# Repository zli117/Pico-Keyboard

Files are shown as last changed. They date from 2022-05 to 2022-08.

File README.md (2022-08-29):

# Pico-Keyboard

A hot-swappable mechanical keyboard built from scratch with Pi Pico board, and 3D printed case, with a very configurable firmware. The firmware is in a separate repo: https://github.com/zli117/PicoMK and can be reused for other RP2040 keyboards.

# Pictures

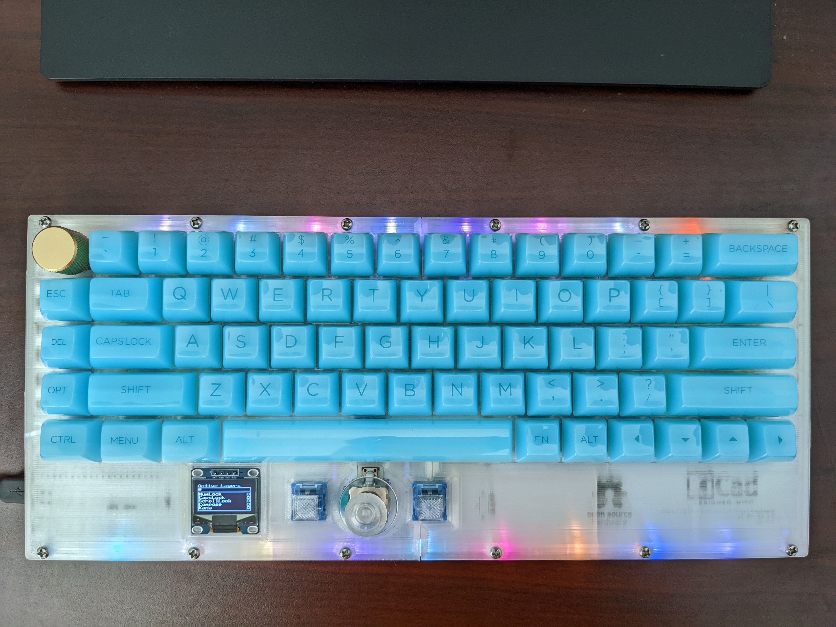
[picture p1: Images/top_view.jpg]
Top View

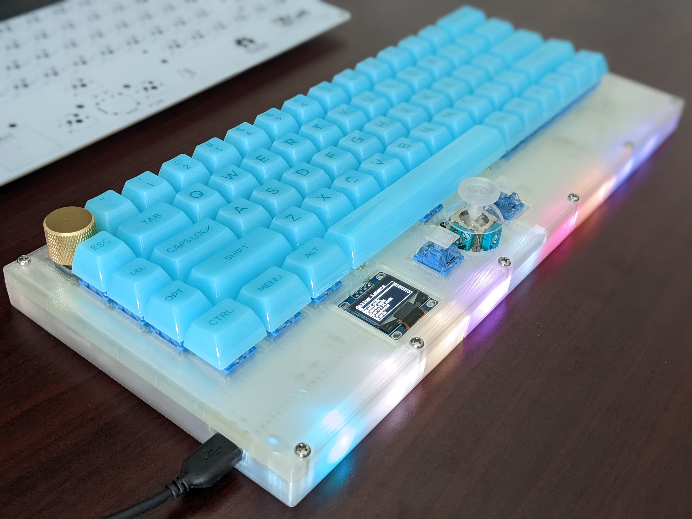
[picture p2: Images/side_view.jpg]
Side View


## PCB

PCB

## Case

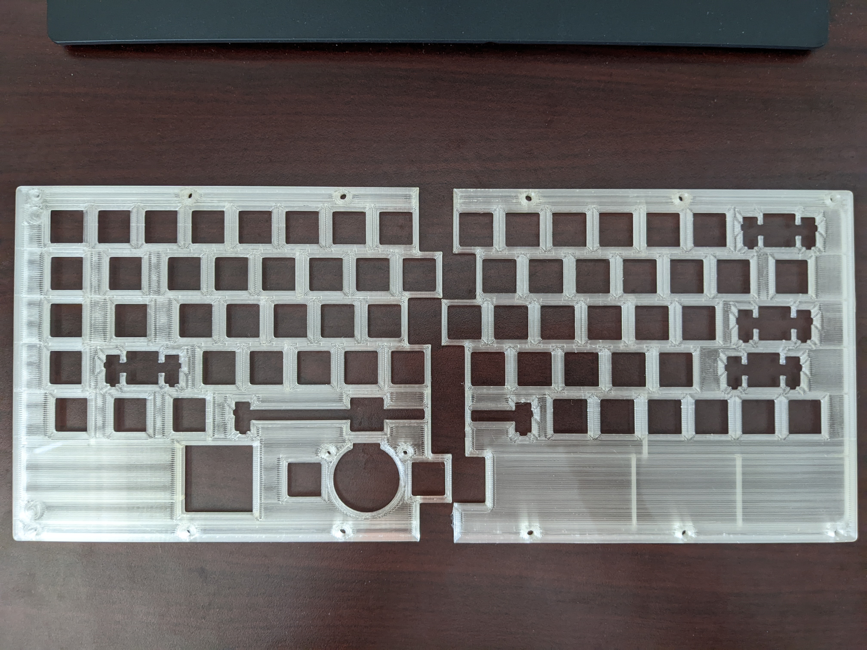
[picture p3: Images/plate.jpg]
Plate

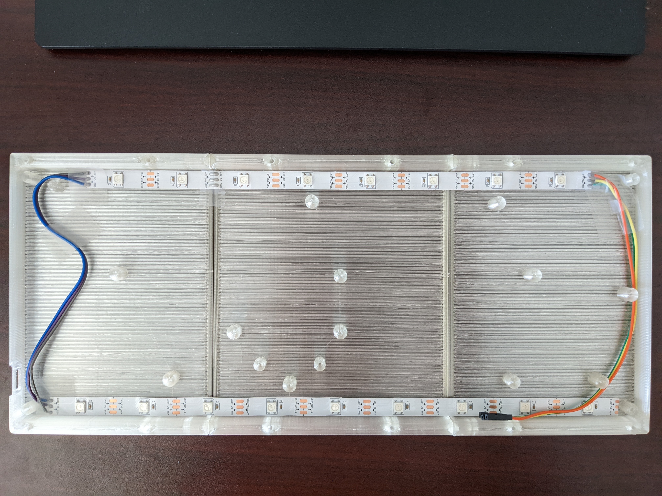
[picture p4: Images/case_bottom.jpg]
Bottom


## Build Pictures

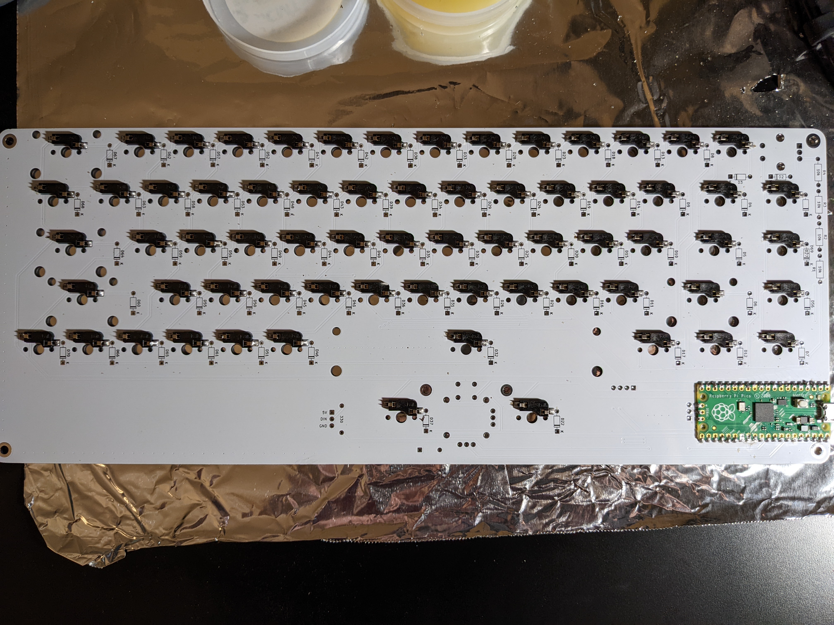
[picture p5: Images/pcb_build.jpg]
PCB Solder

Bottom View

# Overall Cost Breakdown

In total per keyboard material cost is roughly $129.57

 * 5 PCB from JLCPCB with shipping: $39.52. Roughly $7.9 per board.
 * 100 hot-swappable PCB socket: $14.50. Used 68, so total $9.86.
 * Pi Pico: $4.99.
 * EC11 Rotary Encoder: $1.10 each.
 * COM-09032 Joystick: $4.50 each.
 * 100 1N4148 diodes: $4.99. Used 70 so $3.50.
 * 150 WS2812B: $14.49. Used 17, so total $1.64.
 * 3D printed case. Each part weight about 50g and there are 5 (2 for plate, and 3 for bottom). Total weight 250g roughly $6.
 * SSD1306 white color: $3 each.
 * GMMK encoder knob: $10.
 * Clear joystick knob: $5.
 * Stabilizers: $16.99 per set.
 * Akko clear translucent keycap: $39.99.
 * Akko blue switch: $9.99 per 45. Used 68, so total $15.10
 
# Build Instructions

## PCB
PCB is designed with KiCAD 6, and everything is under the [PCB](PCB/) folder. Pre-plotted files that can be uploaded to board factory are in 
`Gerber.zip` file. However, different factory may have different plotting settings, so it's recommended to replot with KiCad following factory's instruction. The provided one is for JLCPCB. 

## Case
Case is designed with Fusion 360. The file ends in `.f3z` contains the original Fusion 360 source. My build used SUNLU Clear PLA and is sliced with Cura. I put screw holes on the bottom to secure the PCB, but in practice it's not necessary to screw down the PCB once you've installed switches. So those are optional. The screws between plate and bottom are not optional however.

## Firmware
Firmware is in a separate repo: [PicoMK](https://github.com/zli117/PicoMK). Please see the instruction on how to configure and build the firmware there. 

# PCB Library Licenses

 * Pico symbol, footprint from https://github.com/ncarandini/KiCad-RP-Pico under CC-BY-SA 4.0. 3D model for Pico is obtained from Raspberry Pi Foundation.
 * COM-09032 symbol, footprint and 3D models are from SnapEDA.
 * Key switch footprints and 3D models are from https://github.com/perigoso/keyswitch-kicad-library 
 * Other symbols are from KiCad library which is under CC-BY-SA 4.0 license. 

This work is licensed under a
[Creative Commons Attribution-ShareAlike 4.0 International License][cc-by-sa].

[][cc-by-sa]

[cc-by-sa]: http://creativecommons.org/licenses/by-sa/4.0/
[cc-by-sa-image]: https://licensebuttons.net/l/by-sa/4.0/88x31.png
[cc-by-sa-shield]: https://img.shields.io/badge/License-CC%20BY--SA%204.0-lightgrey.svg

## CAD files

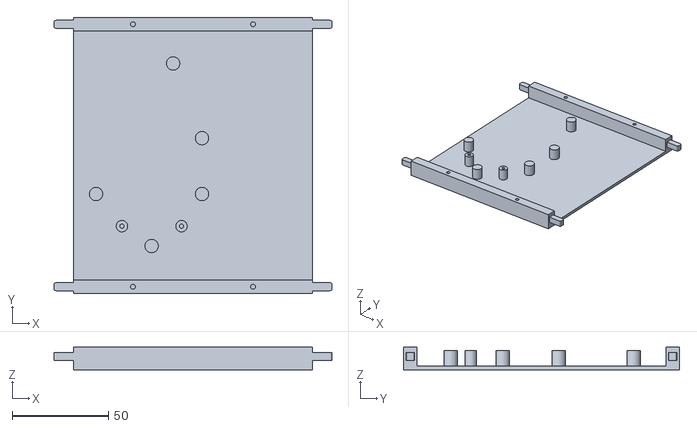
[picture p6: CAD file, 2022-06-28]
Case/base_mid.stl
144.3 x 143.3 x 11.7

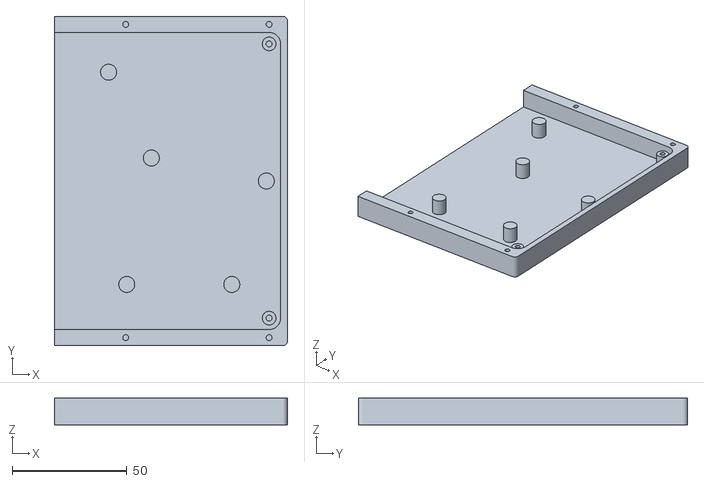
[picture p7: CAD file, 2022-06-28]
Case/base_right.stl
101.3 x 143.3 x 11.7

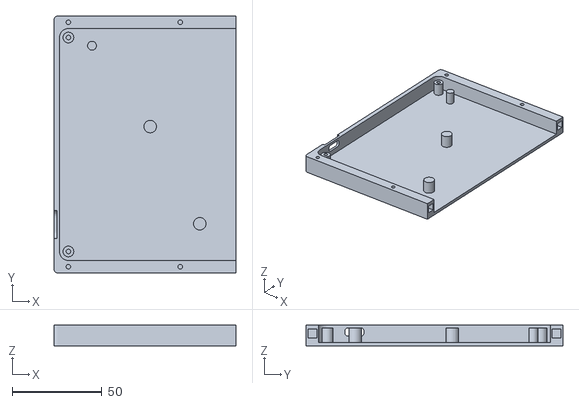
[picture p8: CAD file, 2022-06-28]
Case/base_left.stl
101.3 x 143.3 x 11.7

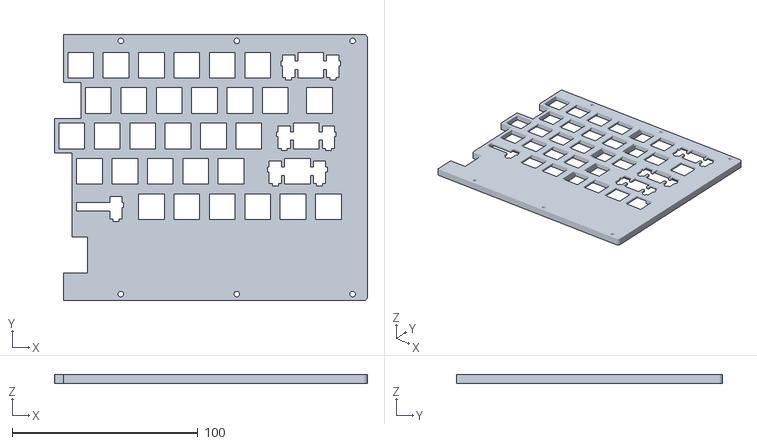
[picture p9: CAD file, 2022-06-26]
Case/plate_right.stl
168.5 x 143.3 x 5.00

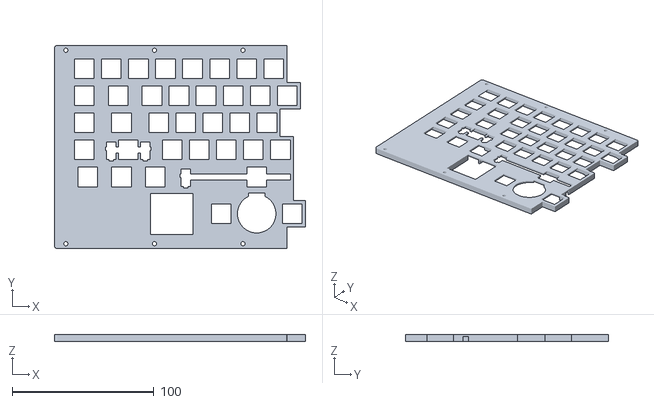
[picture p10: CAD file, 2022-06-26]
Case/plate_left.stl
176.8 x 143.3 x 5.00

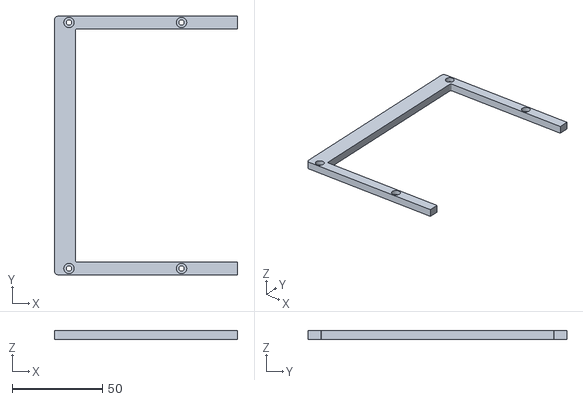
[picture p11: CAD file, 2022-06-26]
Case/ring_left.stl
101.3 x 143.2 x 5.00

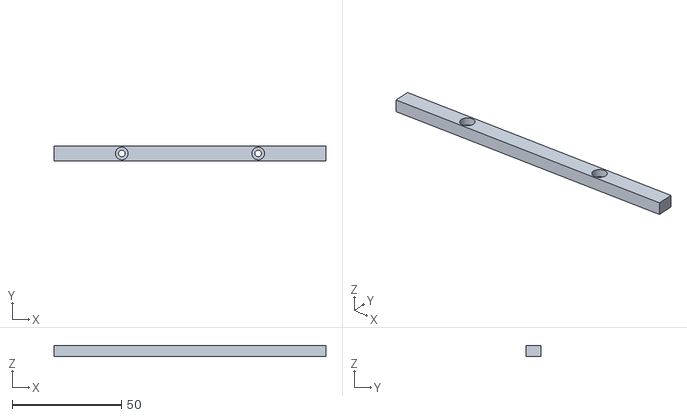
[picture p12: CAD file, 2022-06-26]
Case/ring_mid_top.stl
124.3 x 7.00 x 5.00

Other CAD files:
Case/ring_right.stl
Case/ring_mid_bottom.stl

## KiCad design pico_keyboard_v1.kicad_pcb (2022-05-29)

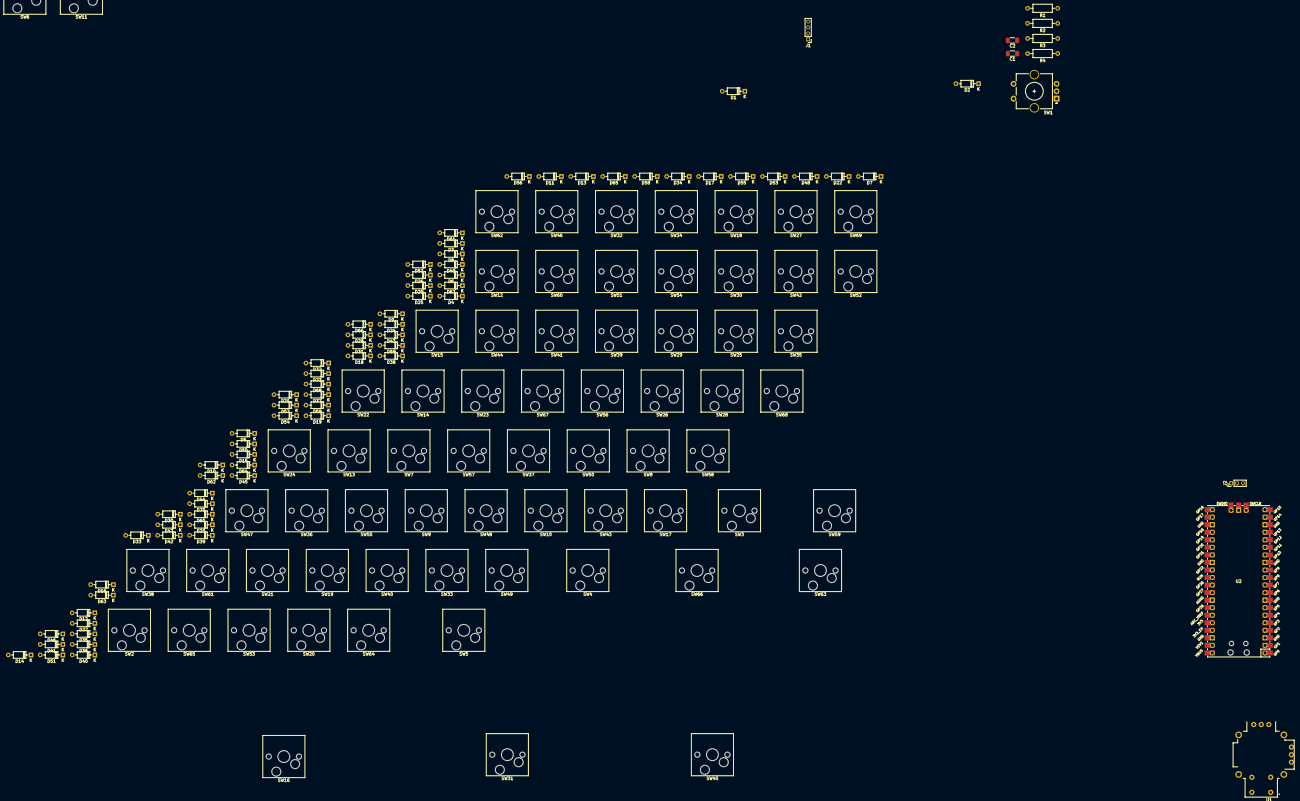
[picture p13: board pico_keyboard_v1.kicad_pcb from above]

Board: 2 copper layers, 149 parts (0 on the bottom side), 103 nets, no tracks yet.

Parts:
C1, C2: 0.01 μF; C_1206_3216Metric_Pad1.33x1.80mm_HandSolder
D1, D2, D3, D4, D5, D6, D7, D8, D9, D10, D11, D12, D13, D14, D15, D16, D17, D18, D19, D20, D21, D22, D23, D24, D25, D26, D27, D28, D29, D30, D31, D32, D33, D34, D35, D36, D37, D38, D39, D40, D41, D42, D43, D44, D45, D46, D47, D48, D49, D50, D51, D52, D53, D54, D55, D56, D57, D58, D59, D60, D61, D62, D63, D64, D65, D66, D67, D68, D69, D70: D; D_DO-35_SOD27_P7.62mm_Horizontal
J1: Conn_01x04_12864; PinHeader_1x04_P2.00mm_Vertical
J2: Conn_01x03_Female; PinHeader_1x03_P2.00mm_Vertical
R1, R2, R3, R4: 10k; R_Axial_DIN0207_L6.3mm_D2.5mm_P10.16mm_Horizontal
SW1: RotaryEncoder_Switch; RotaryEncoder_Alps_EC11E-Switch_Vertical_H20mm_CircularMoun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
SW2: SW_`; SW_Hotswap_Kailh_MX_1.00u
SW3: SW_tab; SW_Hotswap_Kailh_MX_1.50u
SW4: SW_caps; SW_Hotswap_Kailh_MX_1.75u
SW5: SW_shift; SW_Hotswap_Kailh_MX_2.25u
SW6: SW_ctrl; SW_Hotswap_Kailh_MX_1.25u
SW7: SW_1; SW_Hotswap_Kailh_MX_1.00u
SW8: SW_q; SW_Hotswap_Kailh_MX_1.00u
SW9: SW_a; SW_Hotswap_Kailh_MX_1.00u
SW10: SW_z; SW_Hotswap_Kailh_MX_1.00u
SW11: SW_super; SW_Hotswap_Kailh_MX_1.25u
SW12: SW_2; SW_Hotswap_Kailh_MX_1.00u
SW13: SW_w; SW_Hotswap_Kailh_MX_1.00u
SW14: SW_s; SW_Hotswap_Kailh_MX_1.00u
SW15: SW_x; SW_Hotswap_Kailh_MX_1.00u
SW16: SW_alt; SW_Hotswap_Kailh_MX_1.25u
SW17: SW_3; SW_Hotswap_Kailh_MX_1.00u
SW18: SW_e; SW_Hotswap_Kailh_MX_1.00u
SW19: SW_d; SW_Hotswap_Kailh_MX_1.00u
SW20: SW_c; SW_Hotswap_Kailh_MX_1.00u
SW21: SW_m_left; SW_Hotswap_Kailh_MX_1.00u
SW22: SW_4; SW_Hotswap_Kailh_MX_1.00u
SW23: SW_r; SW_Hotswap_Kailh_MX_1.00u
SW24: SW_f; SW_Hotswap_Kailh_MX_1.00u
SW25: SW_v; SW_Hotswap_Kailh_MX_1.00u
SW26: SW_m_middle; SW_Hotswap_Kailh_MX_1.00u
SW27: SW_5; SW_Hotswap_Kailh_MX_1.00u
SW28: SW_t; SW_Hotswap_Kailh_MX_1.00u
SW29: SW_g; SW_Hotswap_Kailh_MX_1.00u
SW30: SW_b; SW_Hotswap_Kailh_MX_1.00u
SW31: SW_space; SW_Hotswap_Kailh_MX_6.25u
SW32: SW_6; SW_Hotswap_Kailh_MX_1.00u
SW33: SW_y; SW_Hotswap_Kailh_MX_1.00u
SW34: SW_h; SW_Hotswap_Kailh_MX_1.00u
SW35: SW_n; SW_Hotswap_Kailh_MX_1.00u
SW36: SW_m_right; SW_Hotswap_Kailh_MX_1.00u
SW37: SW_7; SW_Hotswap_Kailh_MX_1.00u
SW38: SW_u; SW_Hotswap_Kailh_MX_1.00u
SW39: SW_j; SW_Hotswap_Kailh_MX_1.00u
SW40: SW_m; SW_Hotswap_Kailh_MX_1.00u
SW41: SW_8; SW_Hotswap_Kailh_MX_1.00u
SW42: SW_i; SW_Hotswap_Kailh_MX_1.00u
SW43: SW_k; SW_Hotswap_Kailh_MX_1.00u
SW44: SW_,; SW_Hotswap_Kailh_MX_1.00u
SW45: SW_r_ctrl; SW_Hotswap_Kailh_MX_1.00u
SW46: SW_9; SW_Hotswap_Kailh_MX_1.00u
SW47: SW_o; SW_Hotswap_Kailh_MX_1.00u
SW48: SW_l; SW_Hotswap_Kailh_MX_1.00u
SW49: SW_.; SW_Hotswap_Kailh_MX_1.00u
SW50: SW_fn1; SW_Hotswap_Kailh_MX_1.00u
SW51: SW_0; SW_Hotswap_Kailh_MX_1.00u
SW52: SW_p; SW_Hotswap_Kailh_MX_1.00u
SW53: SW_;; SW_Hotswap_Kailh_MX_1.00u
SW54: SW_/; SW_Hotswap_Kailh_MX_1.00u
SW55: SW_fn2; SW_Hotswap_Kailh_MX_1.00u
SW56: SW_-; SW_Hotswap_Kailh_MX_1.00u
SW57: SW_[; SW_Hotswap_Kailh_MX_1.00u
SW58: SW_'; SW_Hotswap_Kailh_MX_1.00u
SW59: SW_r_shift; SW_Hotswap_Kailh_MX_1.75u
SW60: SW_left; SW_Hotswap_Kailh_MX_1.00u
SW61: SW_+; SW_Hotswap_Kailh_MX_1.00u
SW62: SW_]; SW_Hotswap_Kailh_MX_1.00u
SW63: SW_enter; SW_Hotswap_Kailh_MX_2.25u
SW64: SW_up; SW_Hotswap_Kailh_MX_1.00u
SW65: SW_down; SW_Hotswap_Kailh_MX_1.00u
SW66: SW_back; SW_Hotswap_Kailh_MX_2.00u
SW67: SW_\; SW_Hotswap_Kailh_MX_1.00u
SW68: SW_esc; SW_Hotswap_Kailh_MX_1.00u
SW69: SW_right; SW_Hotswap_Kailh_MX_1.00u
U1: COM-09032; XDCR_COM-09032
U2: Pico; RPi_Pico_SMD_TH

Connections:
+3V3: U1.H1 (H+), U1.V1 (V+), U2.36 (3V3)
+5V: J1.1, R1.2, R2.2, U2.39 (VSYS), U2.40 (VBUS)
C0: SW2.2 (B), SW3.2 (B), SW4.2 (B), SW5.2 (B), SW6.2 (B), U2.1 (GPIO0)
C1: SW7.2 (B), SW8.2 (B), SW9.2 (B), SW10.2 (B), SW11.2 (B), U2.2 (GPIO1)
C2: SW12.2 (B), SW13.2 (B), SW14.2 (B), SW15.2 (B), SW16.2 (B), U2.4 (GPIO2)
C3: SW17.2 (B), SW18.2 (B), SW19.2 (B), SW20.2 (B), SW21.2 (B), U2.5 (GPIO3)
C4: SW22.2 (B), SW23.2 (B), SW24.2 (B), SW25.2 (B), SW26.2 (B), U2.6 (GPIO4)
C5: SW27.2 (B), SW28.2 (B), SW29.2 (B), SW30.2 (B), SW31.2 (B), U2.7 (GPIO5)
C6: SW32.2 (B), SW33.2 (B), SW34.2 (B), SW35.2 (B), SW36.2 (B), U2.9 (GPIO6)
C7: SW37.2 (B), SW38.2 (B), SW39.2 (B), SW40.2 (B), U1.B2A (SEL-), U2.10 (GPIO7)
C8: SW41.2 (B), SW42.2 (B), SW43.2 (B), SW44.2 (B), SW45.2 (B), U2.11 (GPIO8)
C9: SW46.2 (B), SW47.2 (B), SW48.2 (B), SW49.2 (B), SW50.2 (B), U2.12 (GPIO9)
C10: SW51.2 (B), SW52.2 (B), SW53.2 (B), SW54.2 (B), SW55.2 (B), U2.14 (GPIO10)
C11: SW56.2 (B), SW57.2 (B), SW58.2 (B), SW59.2 (B), SW60.2 (B), U2.15 (GPIO11)
C12: SW61.2 (B), SW62.2 (B), SW63.2 (B), SW64.2 (B), SW65.2 (B), U2.16 (GPIO12)
C13: SW1.S1, SW66.2 (B), SW67.2 (B), SW68.2 (B), SW69.2 (B), U2.17 (GPIO13)
GND: C1.2, C2.1, J1.2, J2.2, SW1.C, U1.H3 (H-), U1.V3 (V-), U2.3 (GND), U2.8 (GND), U2.13 (GND), U2.18 (GND), U2.23 (GND), U2.28 (GND), U2.38 (GND), U2.42 (GND)
GPIO14: D3.1 (K), D8.1 (K), D13.1 (K), D18.1 (K), D23.1 (K), D28.1 (K), D33.1 (K), D38.1 (K), D42.1 (K), D47.1 (K), D52.1 (K), D57.1 (K), D62.1 (K), D67.1 (K), U2.19 (GPIO14)
GPIO15: D4.1 (K), D9.1 (K), D14.1 (K), D19.1 (K), D24.1 (K), D29.1 (K), D34.1 (K), D39.1 (K), D43.1 (K), D48.1 (K), D53.1 (K), D58.1 (K), D63.1 (K), D68.1 (K), U2.20 (GPIO15)
GPIO16: D5.1 (K), D10.1 (K), D15.1 (K), D20.1 (K), D25.1 (K), D30.1 (K), D35.1 (K), D40.1 (K), D44.1 (K), D49.1 (K), D54.1 (K), D59.1 (K), D64.1 (K), D69.1 (K), U2.21 (GPIO16)
GPIO17: D2.1 (K), D6.1 (K), D11.1 (K), D16.1 (K), D21.1 (K), D26.1 (K), D31.1 (K), D36.1 (K), D41.1 (K), D45.1 (K), D50.1 (K), D55.1 (K), D60.1 (K), D65.1 (K), U2.22 (GPIO17)
GPIO18: D1.1 (K), D7.1 (K), D12.1 (K), D17.1 (K), D22.1 (K), D27.1 (K), D32.1 (K), D37.1 (K), D46.1 (K), D51.1 (K), D56.1 (K), D61.1 (K), D66.1 (K), D70.1 (K), U2.24 (GPIO18)
GPIO19: C1.1, R1.1, R3.2, U2.25 (GPIO19)
GPIO20: J1.4, U2.26 (GPIO20)
GPIO21: J1.3, U2.27 (GPIO21)
GPIO22: C2.2, R2.1, R4.2, U2.29 (GPIO22)
GPIO27: U1.H2 (H), U2.32 (GPIO27_ADC1)
GPIO28: U1.V2 (V), U2.34 (GPIO28_ADC2)
NC: U1.S1 (SHIELD), U1.S2 (SHIELD), U1.S3 (SHIELD), U1.S4 (SHIELD), U2.30 (RUN), U2.33 (AGND), U2.35 (ADC_VREF), U2.37 (3V3_EN)
unnamed: D1.2 (A), U1.B1A (SEL+)
unnamed: D2.2 (A), SW1.S2
unnamed: D3.2 (A), SW2.1 (A)
unnamed: D4.2 (A), SW3.1 (A)
unnamed: D5.2 (A), SW4.1 (A)
unnamed: D6.2 (A), SW5.1 (A)
unnamed: D7.2 (A), SW6.1 (A)
unnamed: D8.2 (A), SW7.1 (A)
unnamed: D9.2 (A), SW8.1 (A)
unnamed: D10.2 (A), SW9.1 (A)
unnamed: D11.2 (A), SW10.1 (A)
unnamed: D12.2 (A), SW11.1 (A)
unnamed: D13.2 (A), SW12.1 (A)
unnamed: D14.2 (A), SW13.1 (A)
unnamed: D15.2 (A), SW14.1 (A)
unnamed: D16.2 (A), SW15.1 (A)
unnamed: D17.2 (A), SW16.1 (A)
unnamed: D18.2 (A), SW17.1 (A)
unnamed: D19.2 (A), SW18.1 (A)
unnamed: D20.2 (A), SW19.1 (A)
unnamed: D21.2 (A), SW20.1 (A)
unnamed: D22.2 (A), SW21.1 (A)
unnamed: D23.2 (A), SW22.1 (A)
unnamed: D24.2 (A), SW23.1 (A)
unnamed: D25.2 (A), SW24.1 (A)
unnamed: D26.2 (A), SW25.1 (A)
unnamed: D27.2 (A), SW26.1 (A)
unnamed: D28.2 (A), SW27.1 (A)
unnamed: D29.2 (A), SW28.1 (A)
unnamed: D30.2 (A), SW29.1 (A)
unnamed: D31.2 (A), SW30.1 (A)
unnamed: D32.2 (A), SW31.1 (A)
unnamed: D33.2 (A), SW32.1 (A)
unnamed: D34.2 (A), SW33.1 (A)
unnamed: D35.2 (A), SW34.1 (A)
unnamed: D36.2 (A), SW35.1 (A)
unnamed: D37.2 (A), SW36.1 (A)
unnamed: D38.2 (A), SW37.1 (A)
unnamed: D39.2 (A), SW38.1 (A)
unnamed: D40.2 (A), SW39.1 (A)
unnamed: D41.2 (A), SW40.1 (A)
unnamed: D42.2 (A), SW41.1 (A)
unnamed: D43.2 (A), SW42.1 (A)
unnamed: D44.2 (A), SW43.1 (A)
unnamed: D45.2 (A), SW44.1 (A)
unnamed: D46.2 (A), SW45.1 (A)
unnamed: D47.2 (A), SW46.1 (A)
unnamed: D48.2 (A), SW47.1 (A)
unnamed: D49.2 (A), SW48.1 (A)
unnamed: D50.2 (A), SW49.1 (A)
unnamed: D51.2 (A), SW50.1 (A)
unnamed: D52.2 (A), SW51.1 (A)
unnamed: D53.2 (A), SW52.1 (A)
unnamed: D54.2 (A), SW53.1 (A)
unnamed: D55.2 (A), SW54.1 (A)
unnamed: D56.2 (A), SW55.1 (A)
unnamed: D57.2 (A), SW56.1 (A)
unnamed: D58.2 (A), SW57.1 (A)
unnamed: D59.2 (A), SW58.1 (A)
unnamed: D60.2 (A), SW59.1 (A)
unnamed: D61.2 (A), SW60.1 (A)
unnamed: D62.2 (A), SW61.1 (A)
unnamed: D63.2 (A), SW62.1 (A)
unnamed: D64.2 (A), SW63.1 (A)
unnamed: D65.2 (A), SW64.1 (A)
unnamed: D66.2 (A), SW65.1 (A)
unnamed: D67.2 (A), SW66.1 (A)
unnamed: D68.2 (A), SW67.1 (A)
unnamed: D69.2 (A), SW68.1 (A)
unnamed: D70.2 (A), SW69.1 (A)
unnamed: J2.1, U2.43 (SWDIO)
unnamed: J2.3, U2.41 (SWCLK)
unnamed: R3.1, SW1.A
unnamed: R4.1, SW1.B

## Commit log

2022-05-29 More changes
    [pico_keyboard_v1.kicad_pcb, pico_keyboard_v1.kicad_sch]
2022-05-30 More polished. Added mounting hole and led
    [pico_keyboard_v1-B_Cu.gbr, pico_keyboard_v1-B_Mask.gbr, pico_keyboard_v1-B_Paste.gbr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]
2022-05-30 Moved diode text to back
2022-05-30 V1, before a major change
    [pico_keyboard_v1.kicad_sch, switch_matrix.kicad_sch]
2022-05-31 New version
    [pico_keyboard_v1.kicad_sch, switch_matrix.kicad_sch]
2022-05-31 Rounded corners
    [pico_keyboard_v1.kicad_sch]
2022-06-01 V0.2. Before another major redesign
    [pico_keyboard_v1-B_Cu.gbr, pico_keyboard_v1-B_Mask.gbr, pico_keyboard_v1-B_Paste.gbr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]
2022-06-02 Updated edge cut layer
    [pico_keyboard_v1-B_Mask.dxf, pico_keyboard_v1-B_Paste.dxf, pico_keyboard_v1-B_Silkscreen.dxf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]
2022-06-02 Removed plot
    [pico_keyboard_v1-B_Mask.dxf, pico_keyboard_v1-B_Paste.dxf, pico_keyboard_v1-B_Silkscreen.dxf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]
2022-06-02 Added some logos
    [pico_keyboard_v1.kicad_sch]
2022-06-02 Changed github repo name
    [pico_keyboard_v1.kicad_sch]
2022-06-12 Changed layout a bit. Starting of V0.4
    [pico_keyboard_v1.kicad_sch]
2022-06-12 New plots
    [pico_keyboard_v1-B_Cu.gbl, pico_keyboard_v1-B_Mask.gbs, pico_keyboard_v1-B_Paste.gbp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]
2022-06-12 Updated the location of a silkscreen
2022-06-21 Moved project to PCB dir
    [pico_keyboard_v1-B_Cu.gbl, pico_keyboard_v1-B_Mask.gbs, pico_keyboard_v1-B_Paste.gbp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]
2022-06-21 Updated pcb images
2022-06-21 Added license information for pcb libraries
2022-06-26 Updated 3d model and gerber
    [base_left.stl, base_mid.stl, base_right.stl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]
2022-06-26 Fixing some 3d model dimension issues
    [base_left.stl, base_mid.stl, base_right.stl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]
2022-06-27 Renamed dir
    [base_left.stl, base_mid.stl, base_right.stl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]
2022-06-28 Updated case model to hopefully fix the connector issues
    [base_left.stl, base_mid.stl, base_right.stl]
2022-07-02 Fixed the RC filter for rotary encoder
    [pico_keyboard_v1-B_Cu.gbl, pico_keyboard_v1-B_Mask.gbs, pico_keyboard_v1-B_Paste.gbp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]
2022-07-02 Changed the routing a bit
    [pico_keyboard_v1-B_Cu.gbl, pico_keyboard_v1-B_Mask.gbs, pico_keyboard_v1-B_Paste.gbp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]
2022-10-16 Started working on v0.5
    [pico_keyboard_v1.kicad_sch, switch_matrix.kicad_sch]
2022-10-17 Updated pico footprint to remove warnings
2022-10-17 Use both types of joystick
    [pico_keyboard_v1.kicad_sch, switch_matrix.kicad_sch]

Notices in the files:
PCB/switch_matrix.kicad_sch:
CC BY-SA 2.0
